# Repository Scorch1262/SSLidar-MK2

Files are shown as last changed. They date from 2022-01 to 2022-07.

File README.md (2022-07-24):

# SSLidar-MK2
Solid State Lidar

 Funktionen (Software V1.0) [F]:
	( Ab Board V2.0 )
- MCC UART1 Funktion
- MCC I2C Funktion
- MCC SPI Funktion
- MCC Fatfs Funktion
- Sensorauswertung 8x Time-of-Flight (VL53L0X)
- Speicherung der Sensordaten auf der SD-Karte
- Weitergabe/Verteilung von UART Signalen

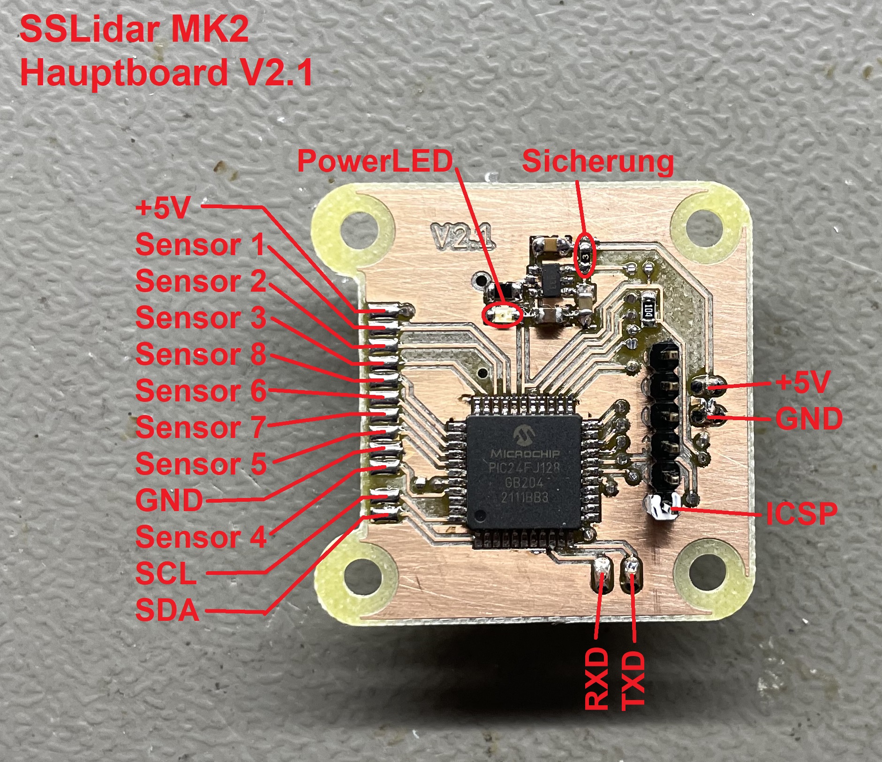
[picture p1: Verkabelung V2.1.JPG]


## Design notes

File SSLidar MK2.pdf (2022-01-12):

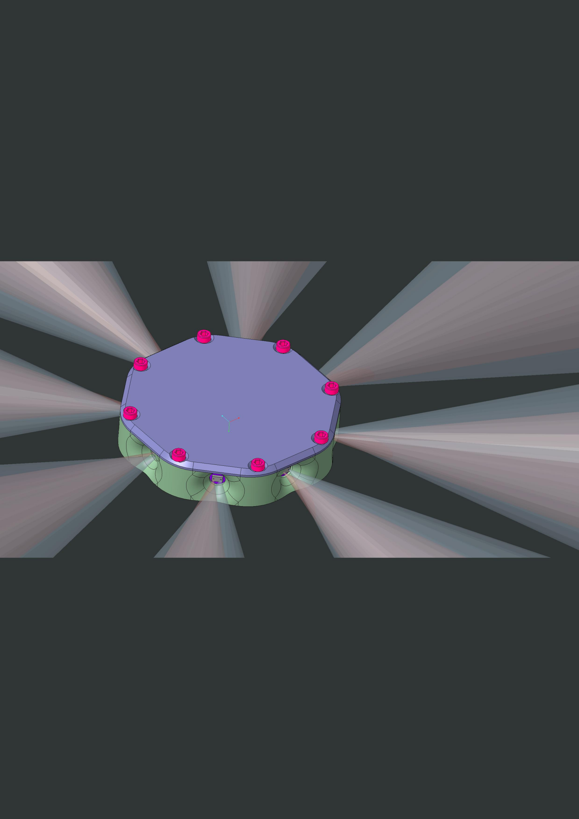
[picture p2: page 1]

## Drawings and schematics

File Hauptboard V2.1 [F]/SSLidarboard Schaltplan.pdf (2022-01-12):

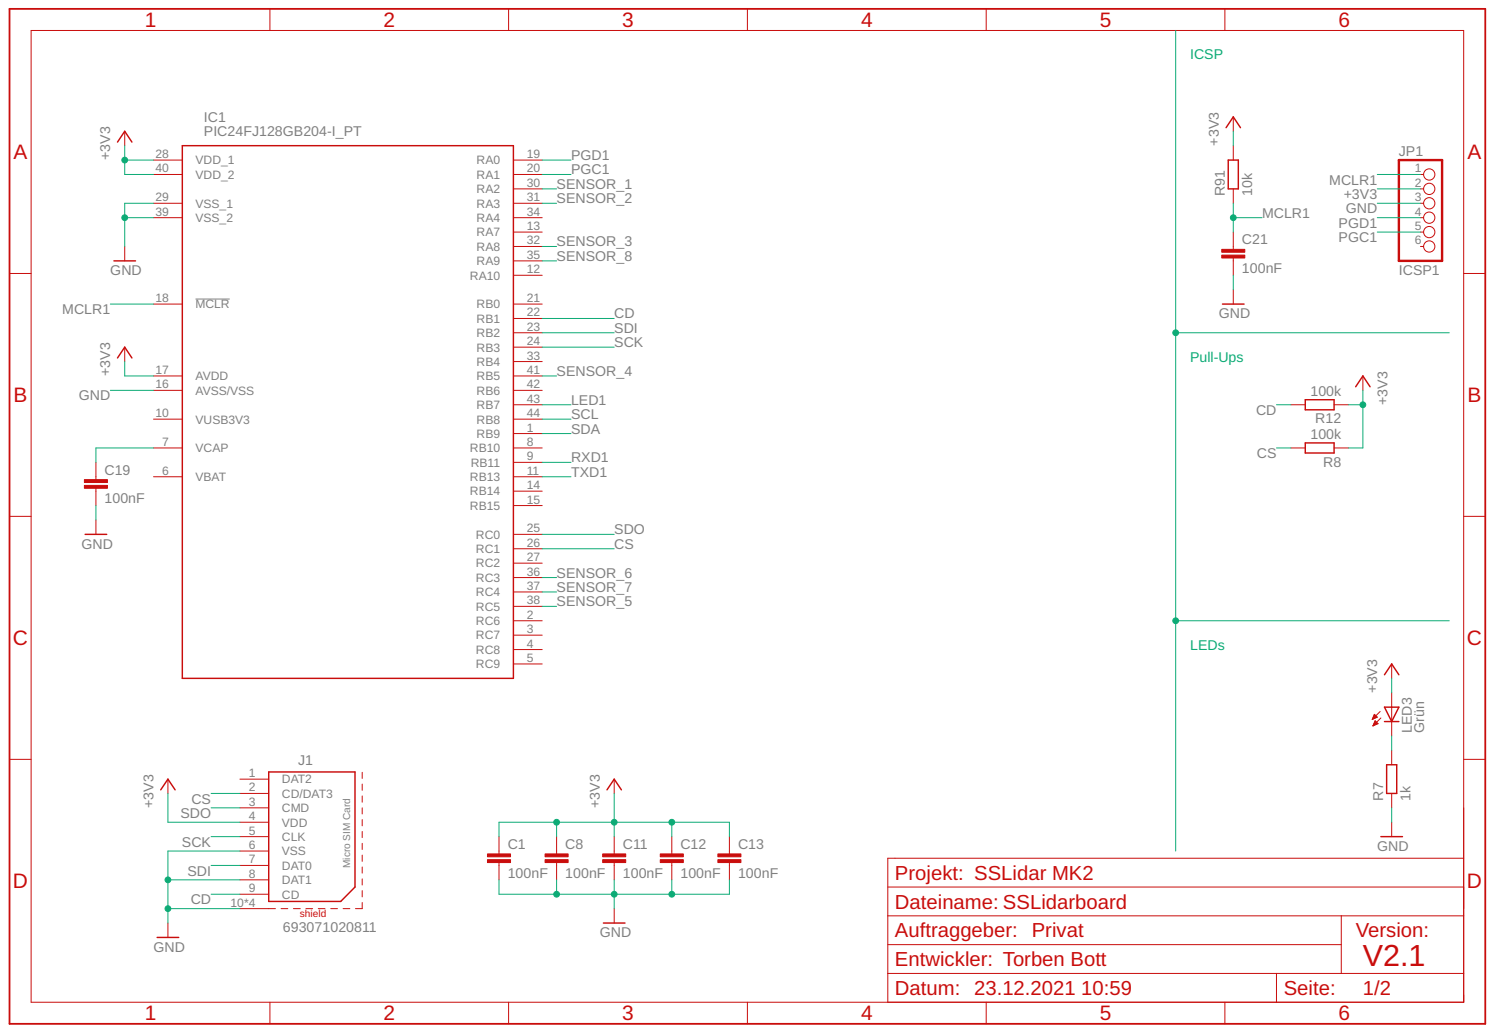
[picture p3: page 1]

Micro SIM Card +3V3 GND 100nF +3V3 GND 100nF 100nF 100nF 100nF +3V3 GND 100nF 100k 100k +3V3 +3V3 GND100nF 10k PIC24FJ128GB204-I_PT ICSP1 GND Grün 1k +3V3 693071020811 GND +3V3 C1 C8 C11 C12 C13 C19 R8 R12 C21 R91 RB9 1 RC6 2 RC7 3 RC8 4 RC9 5 VBAT 6 VCAP 7 RB10 8 RB11 9 VUSB3V3 10 RB13 11 RA10 12 RA7 13 RB14 14 RB15 15 AVSS/VSS 16 AVDD 17 MCLR 18 RA0 19 RA1 20 RB0 21 RB1 22 RB4 33 RA8 32 RA3 31 RA2 30 VSS_1 29 VDD_1 28 RC2 27 RC1 26 RC0 25 RB3 24 RB2 23 RB8 44 RB7 43 RB6 42 RB5 41 VDD_2 40 VSS_2 39 RC5 38 RC4 37 RC3 36 RA9 35 RA4 34 IC1 123456 JP1LED3 R7DAT2 1 CD/DAT3 2 CMD 3 VDD 4 CLK 5 VSS 6 DAT0 7 DAT1 8 CD 9 10*4 J1 +3V3 GND GND LED1 SCK SCK CS CS CS SDO SDO SDI SDI CD CD CD SCL SDA PGD1 PGD1 PGC1 PGC1 MCLR1 MCLR1 MCLR1 RXD1 TXD1 SENSOR_4 SENSOR_3 SENSOR_2 SENSOR_1 SENSOR_5 SENSOR_6 SENSOR_7 SENSOR_8 SSLidar MK2 Privat Torben Bott V2.1 ABCD 1 2 3 4 5 6 ABCD 1 2 3 4 5 6 Datum: Seite: Version: Dateiname: Auftraggeber: Entwickler: Projekt: 23.12.2021 10:59 1/2 SSLidarboard shield LEDs ICSP Pull-Ups

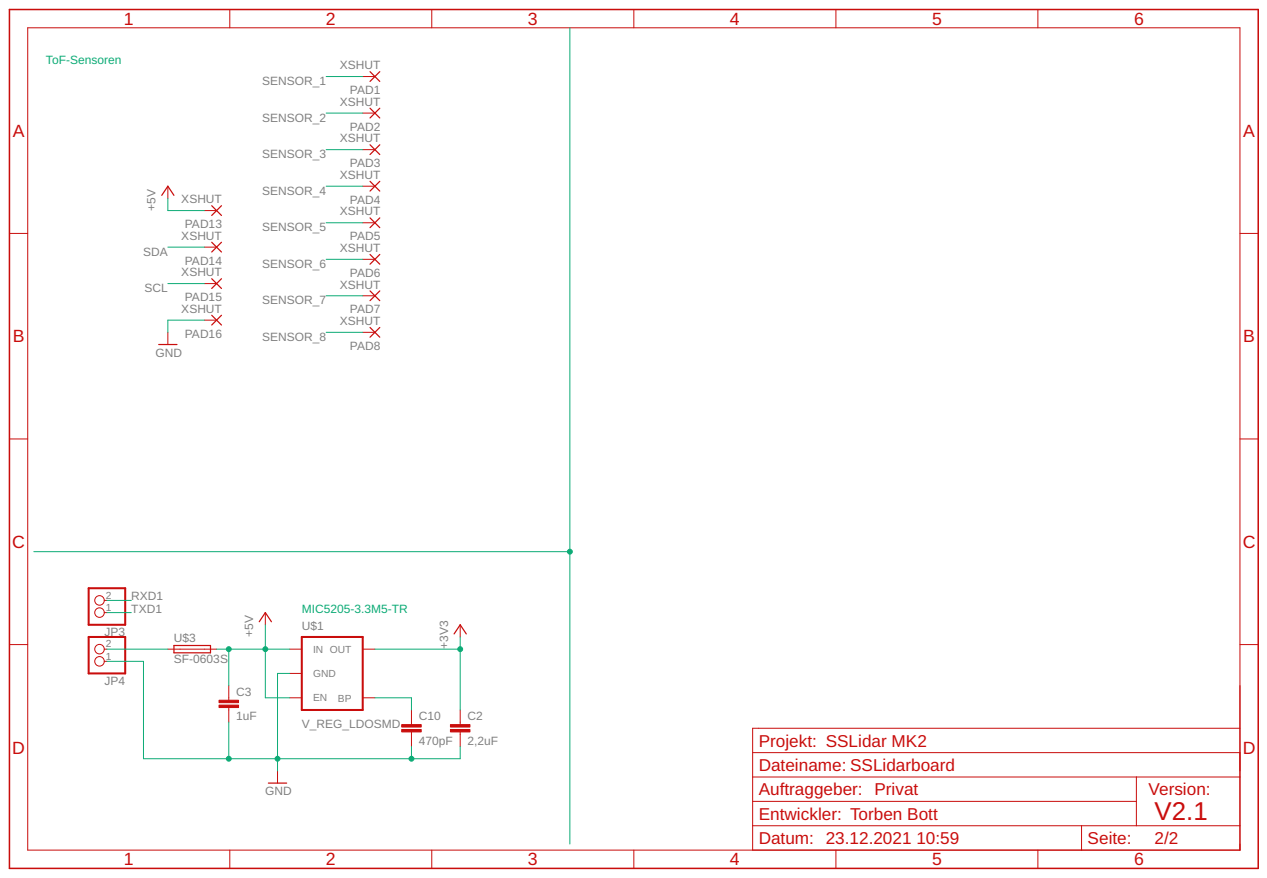
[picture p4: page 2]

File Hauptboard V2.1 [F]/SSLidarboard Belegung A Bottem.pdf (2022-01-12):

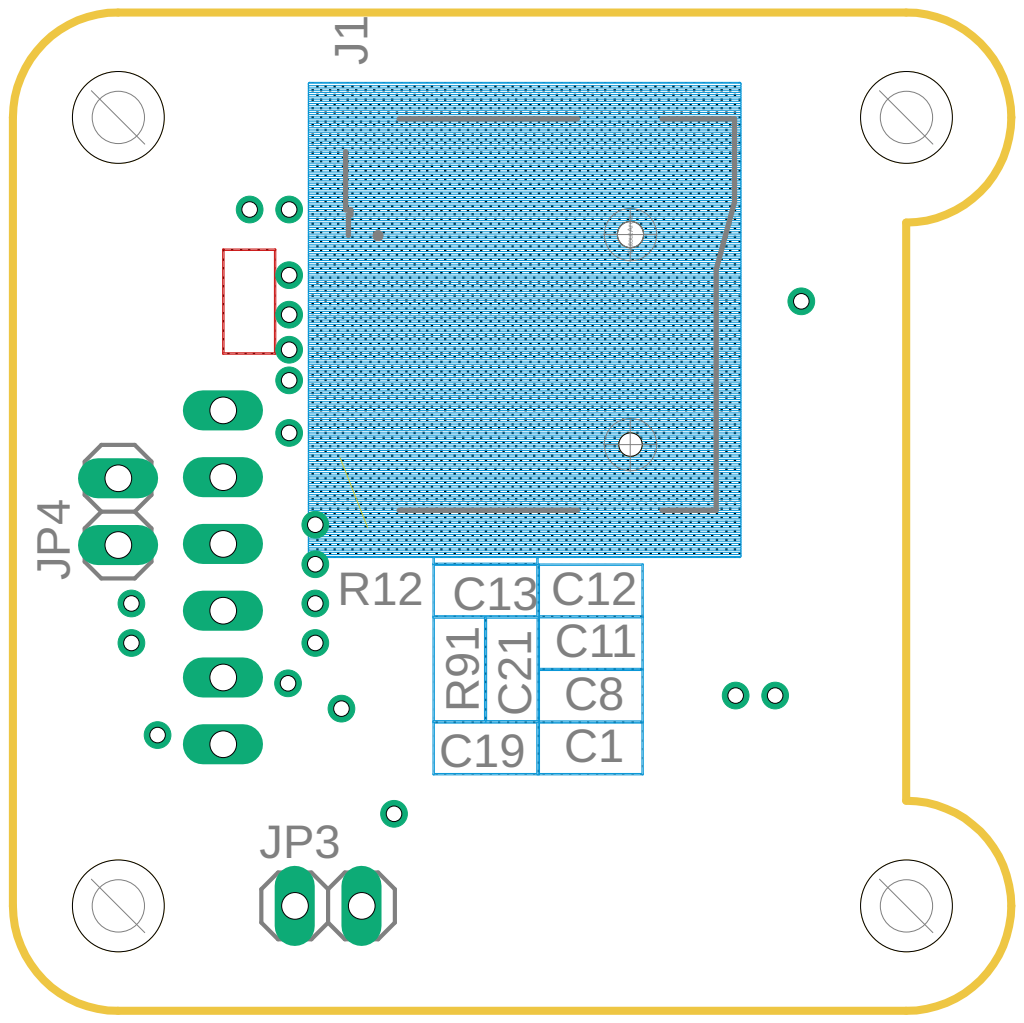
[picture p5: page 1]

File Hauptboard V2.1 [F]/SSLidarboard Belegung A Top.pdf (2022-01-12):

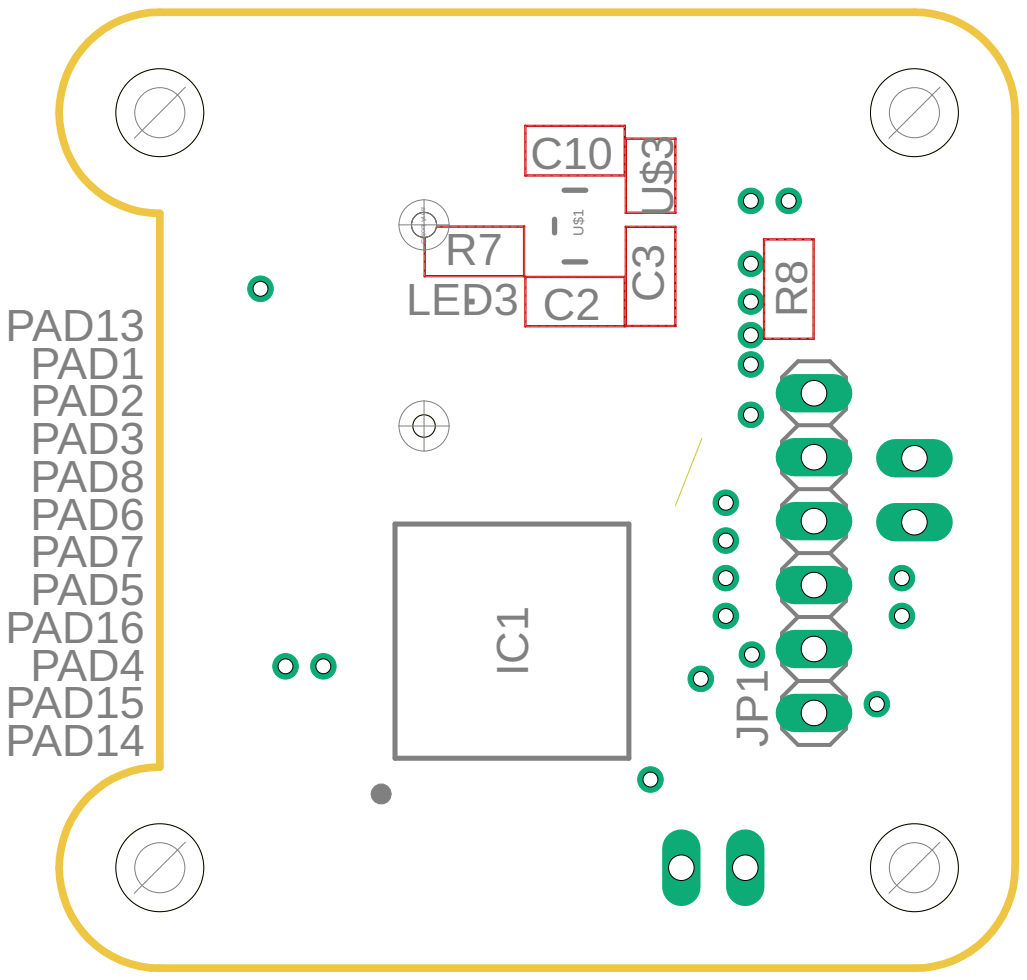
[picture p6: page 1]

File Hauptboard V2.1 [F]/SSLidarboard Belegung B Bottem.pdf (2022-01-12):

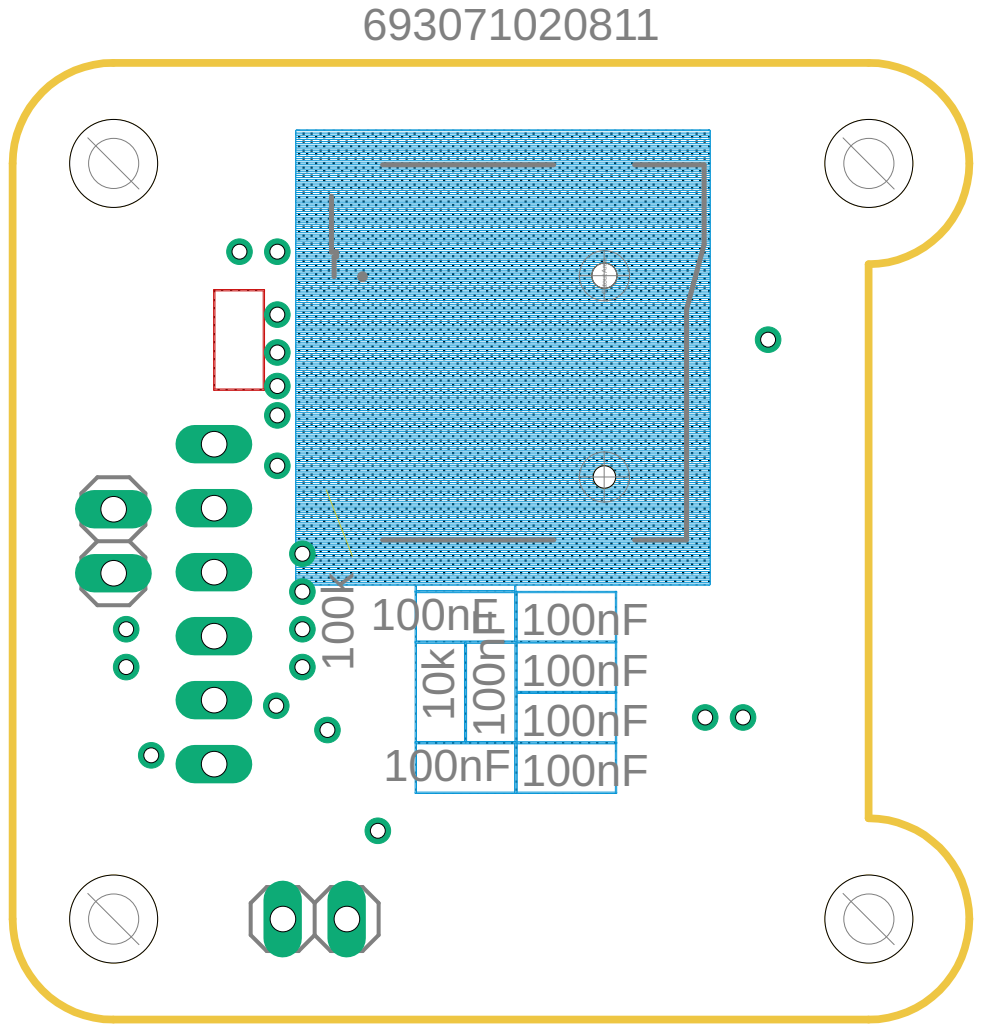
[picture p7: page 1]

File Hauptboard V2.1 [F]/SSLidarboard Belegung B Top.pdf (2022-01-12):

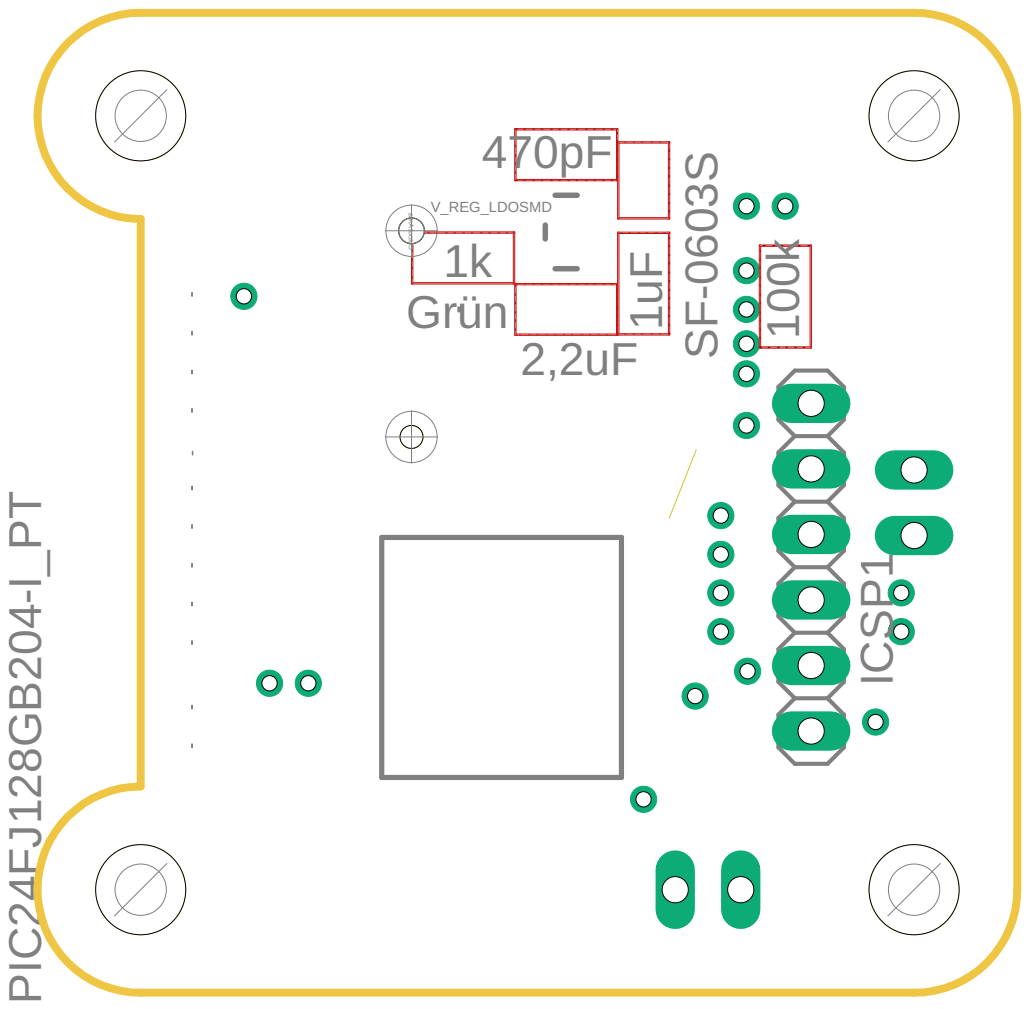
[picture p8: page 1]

100k PIC24FJ128GB204-I_PT ICSP1 Grün 1k V_REG_LDOSMD 2,2uF 470pF 1uF SF-0603S Cutout Area

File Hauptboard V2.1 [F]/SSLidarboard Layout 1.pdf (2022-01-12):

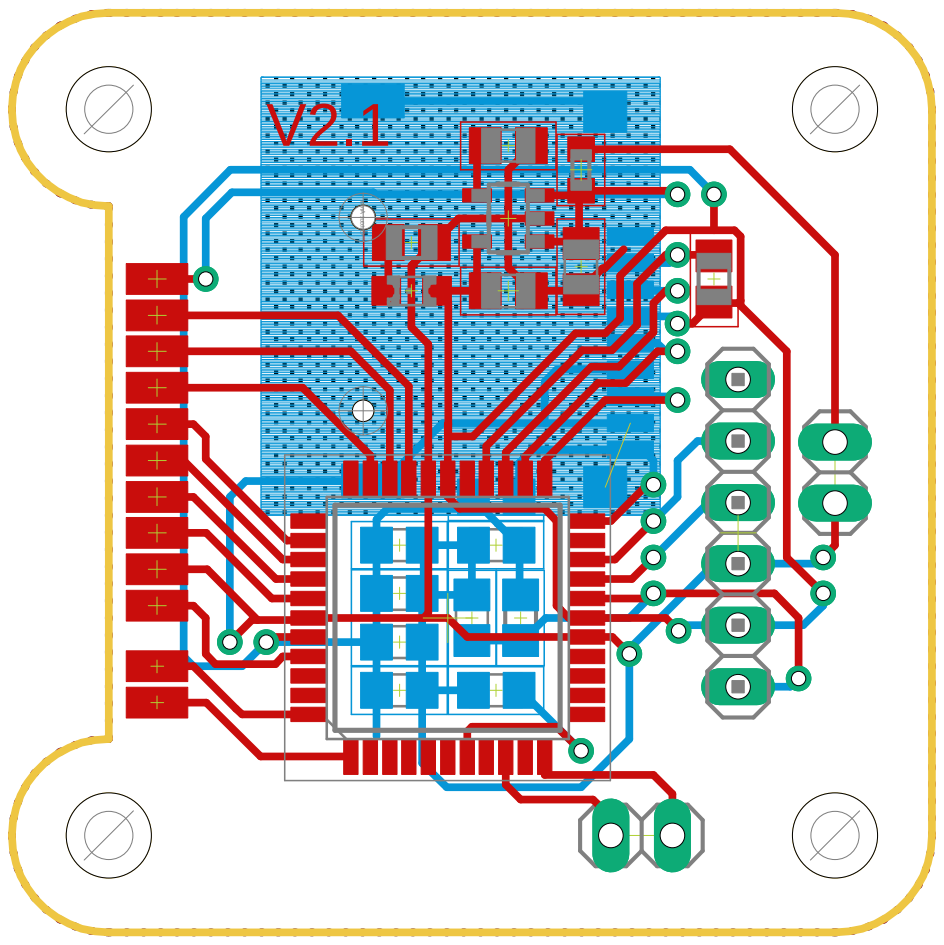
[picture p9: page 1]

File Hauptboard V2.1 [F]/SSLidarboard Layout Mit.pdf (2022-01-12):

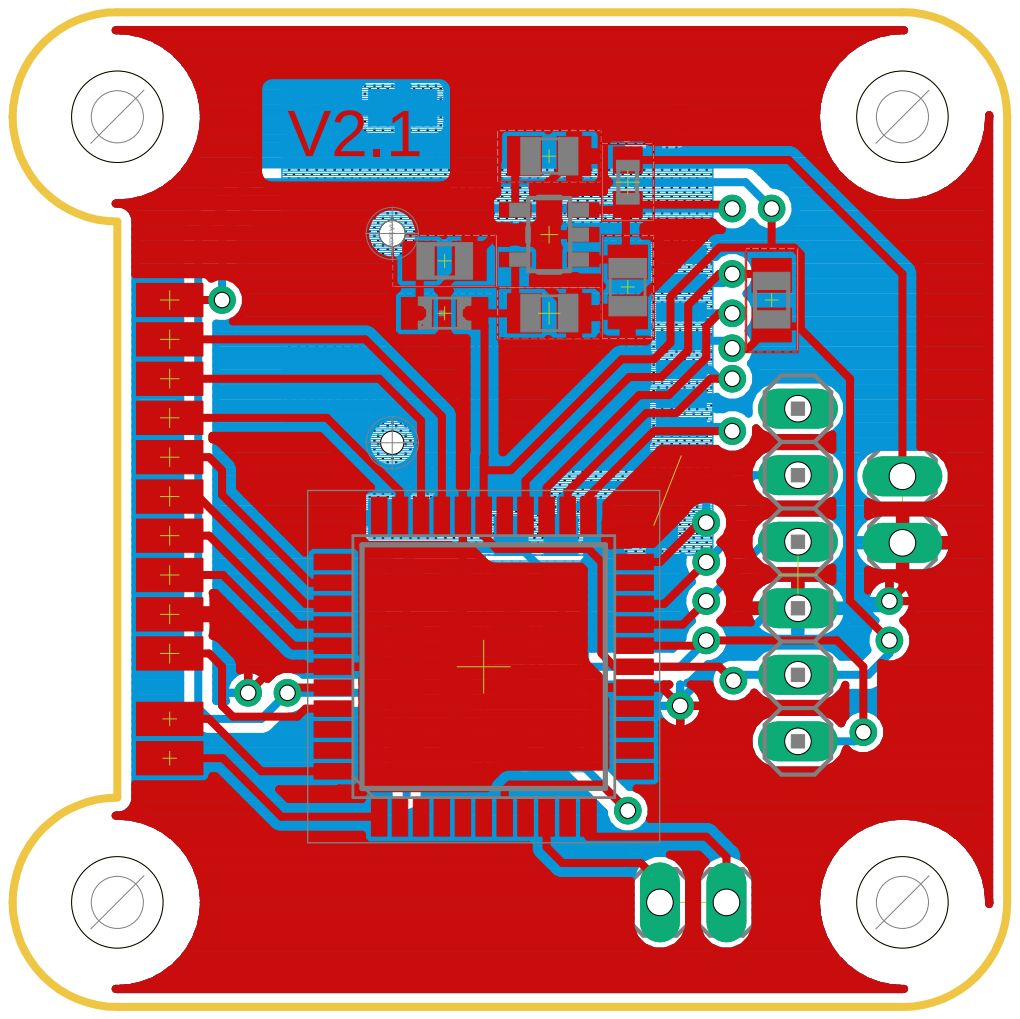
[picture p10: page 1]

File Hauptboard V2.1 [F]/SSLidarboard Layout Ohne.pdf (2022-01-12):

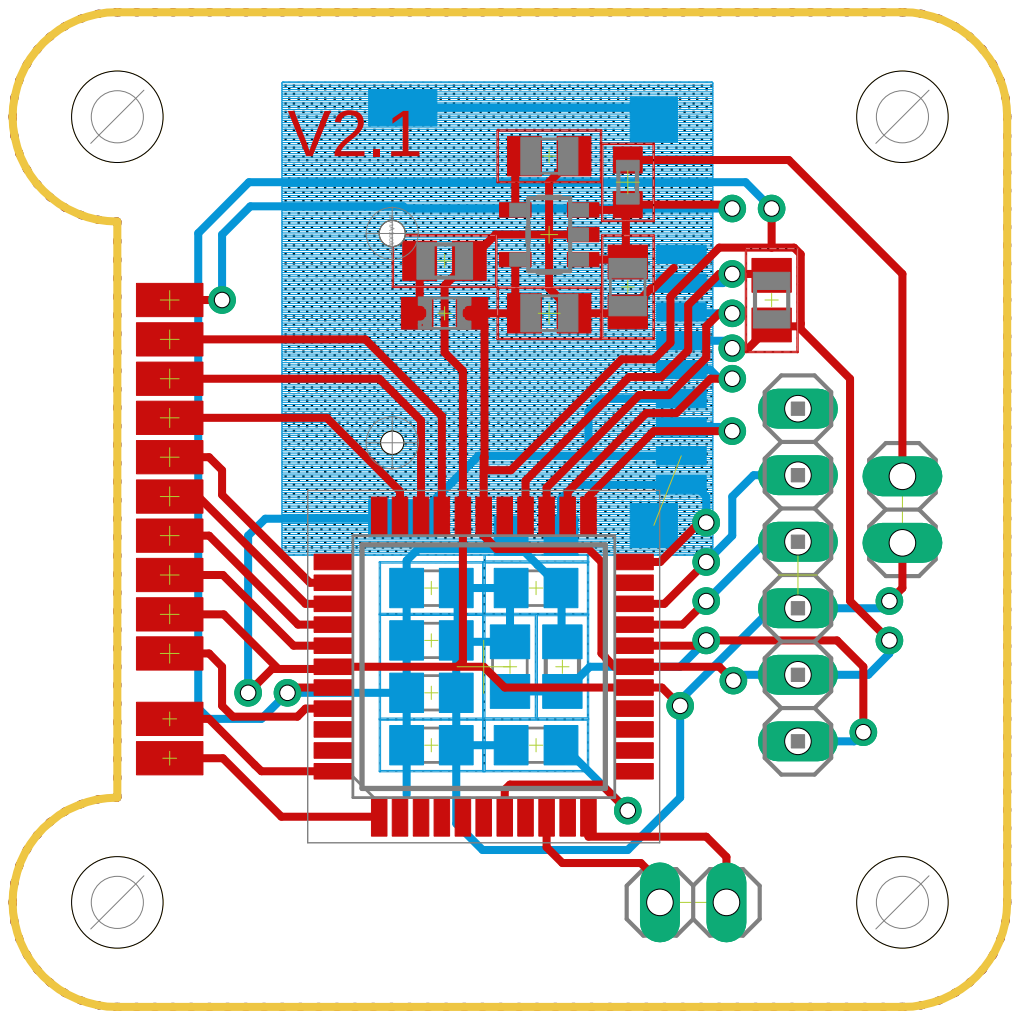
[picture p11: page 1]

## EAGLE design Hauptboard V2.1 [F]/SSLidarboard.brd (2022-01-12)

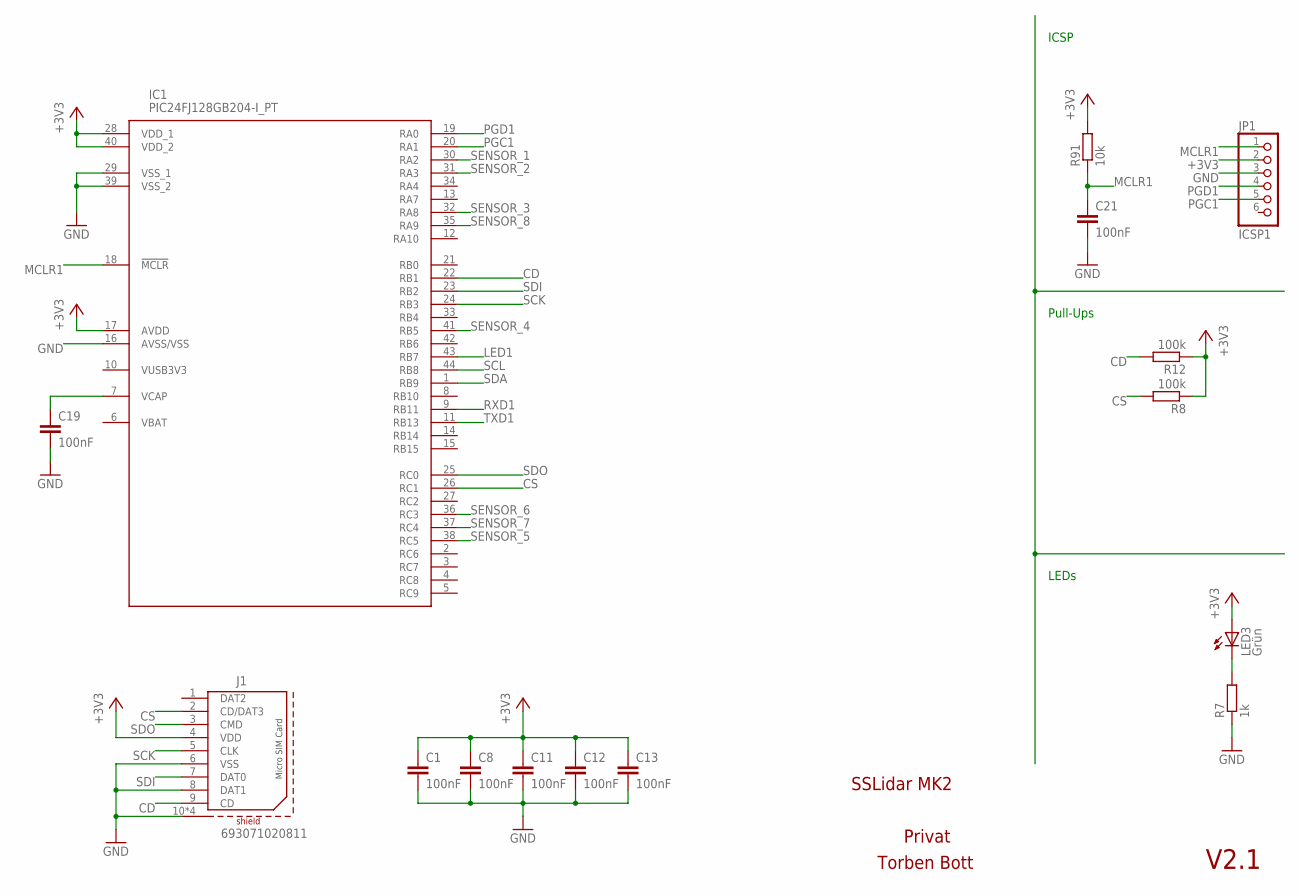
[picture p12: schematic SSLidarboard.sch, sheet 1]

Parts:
C1, C8, C11, C12, C13, C19, C21: 100nF; C0805
IC1: PIC24FJ128GB204-I_PT; QFP80P1200X1200X120-44N
J1: 693071020811
JP1: ICSP1; 1X06
LED3: Grün; CHIPLED_0805
R7: 1k; R0805
R8, R12: 100k; R0805
R91: 10k; R0805

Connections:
+3V3: C1.1, C8.1, C11.1, C12.1, C13.1, IC1.17 (AVDD), IC1.28 (VDD_1), IC1.40 (VDD_2), J1.4 (VDD), JP1.2, LED3.A, R8.1, R12.1, R91.2; also elsewhere on the board
CD: IC1.22 (RB1), J1.9 (CD), R12.2
CS: IC1.26 (RC1), J1.2 (CD/DAT3), R8.2
GND: C1.2, C8.2, C11.2, C12.2, C13.2, C19.2, C21.2, IC1.16 (AVSS/VSS), IC1.29 (VSS_1), IC1.39 (VSS_2), J1.6 (VSS), J1.8 (DAT1), J1.10 (SHIELD), J1.11 (SHIELD), J1.12 (SHIELD), J1.13 (SHIELD), JP1.3, R7.1; also elsewhere on the board
LED1: IC1.43 (RB7)
MCLR1: C21.1, IC1.18 (!MCLR), JP1.1, R91.1
unnamed: LED3.C, R7.2
unnamed: C19.1, IC1.7 (VCAP)
PGC1: IC1.20 (RA1), JP1.5
PGD1: IC1.19 (RA0), JP1.4
RXD1: IC1.9 (RB11); also elsewhere on the board
SCK: IC1.24 (RB3), J1.5 (CLK)
SCL: IC1.44 (RB8); also elsewhere on the board
SDA: IC1.1 (RB9); also elsewhere on the board
SDI: IC1.23 (RB2), J1.7 (DAT0)
SDO: IC1.25 (RC0), J1.3 (CMD)
SENSOR_1: IC1.30 (RA2); also elsewhere on the board
SENSOR_2: IC1.31 (RA3); also elsewhere on the board
SENSOR_3: IC1.32 (RA8); also elsewhere on the board
SENSOR_4: IC1.41 (RB5); also elsewhere on the board
SENSOR_5: IC1.38 (RC5); also elsewhere on the board
SENSOR_6: IC1.36 (RC3); also elsewhere on the board
SENSOR_7: IC1.37 (RC4); also elsewhere on the board
SENSOR_8: IC1.35 (RA9); also elsewhere on the board
TXD1: IC1.11 (RB13); also elsewhere on the board

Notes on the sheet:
SSLidar MK2
Privat
Torben Bott
V2.1
LEDs
ICSP
Pull-Ups

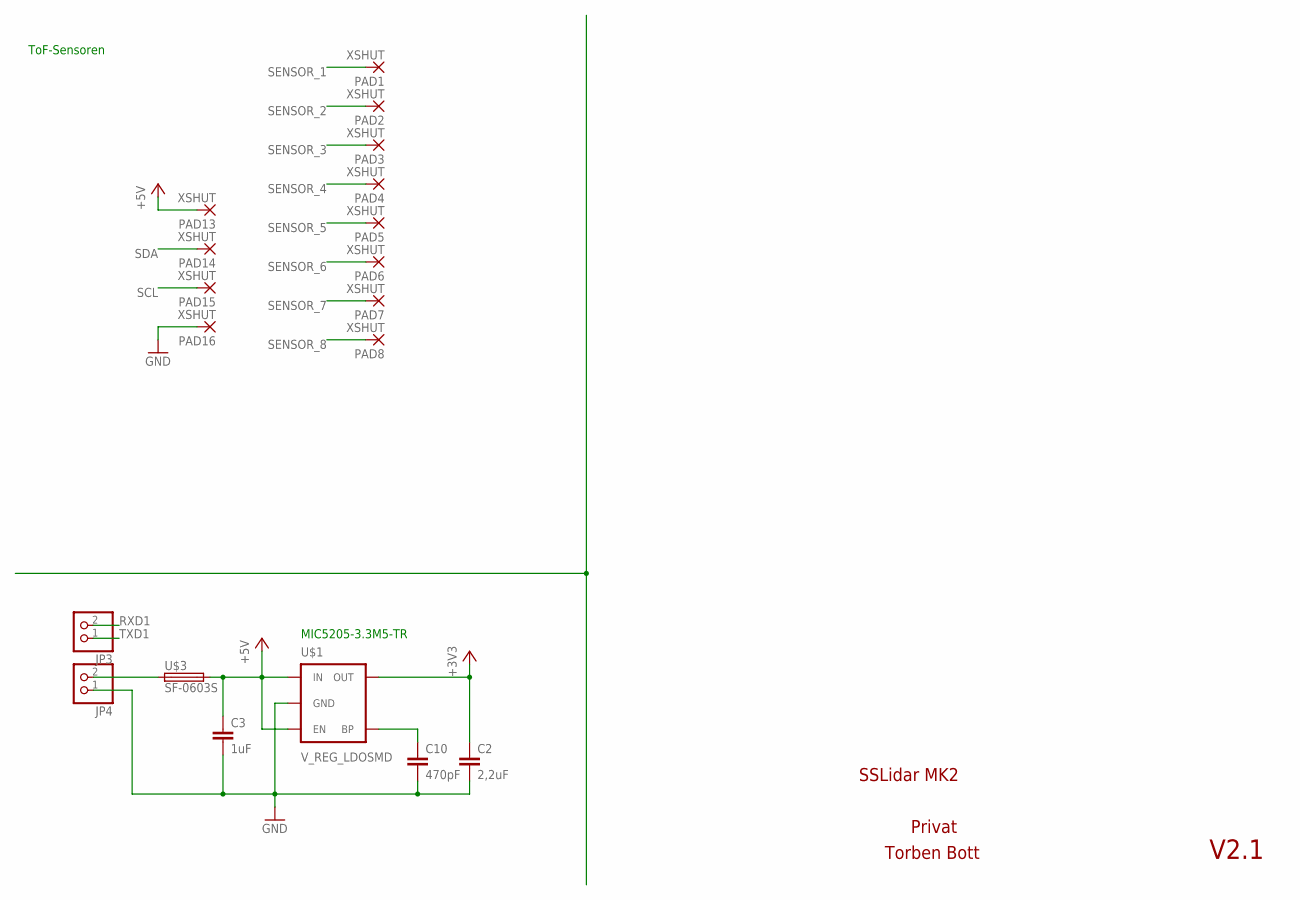
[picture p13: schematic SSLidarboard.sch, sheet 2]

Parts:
C2: 2,2uF; C0805
C3: 1uF; C0805
C10: 470pF; C0805
JP3, JP4: PINHD-1X2; 1X02
PAD1, PAD2, PAD3, PAD4, PAD5, PAD6, PAD7, PAD8, PAD13, PAD14, PAD15, PAD16: XSHUT; SMD1,27-2,54
U$1: V_REG_LDOSMD; SOT23-5
U$3: SF-0603S; R0603

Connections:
+3V3: C2.1, U$1.5 (OUT); also elsewhere on the board
+5V: C3.1, PAD13.1, U$1.1 (IN), U$1.3 (EN), U$3.2
GND: C2.2, C3.2, C10.2, JP4.1, PAD16.1, U$1.2 (GND); also elsewhere on the board
unnamed: JP4.2, U$3.1
unnamed: C10.1, U$1.4 (BP)
RXD1: JP3.2; also elsewhere on the board
SCL: PAD15.1; also elsewhere on the board
SDA: PAD14.1; also elsewhere on the board
SENSOR_1: PAD1.1; also elsewhere on the board
SENSOR_2: PAD2.1; also elsewhere on the board
SENSOR_3: PAD3.1; also elsewhere on the board
SENSOR_4: PAD4.1; also elsewhere on the board
SENSOR_5: PAD5.1; also elsewhere on the board
SENSOR_6: PAD6.1; also elsewhere on the board
SENSOR_7: PAD7.1; also elsewhere on the board
SENSOR_8: PAD8.1; also elsewhere on the board
TXD1: JP3.1; also elsewhere on the board

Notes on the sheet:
Privat
Torben Bott
V2.1
ToF-Sensoren
SSLidar MK2
MIC5205-3.3M5-TR

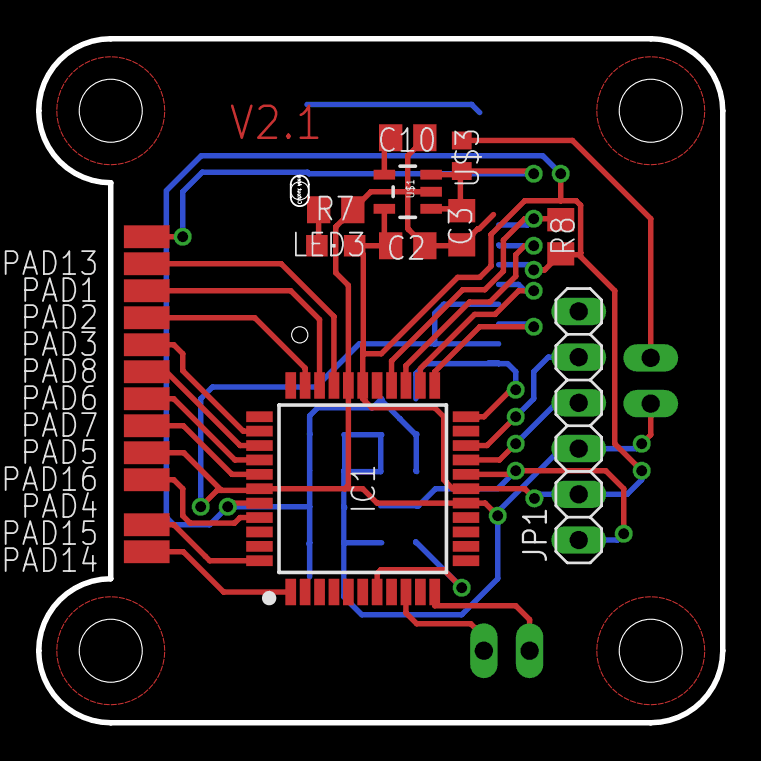
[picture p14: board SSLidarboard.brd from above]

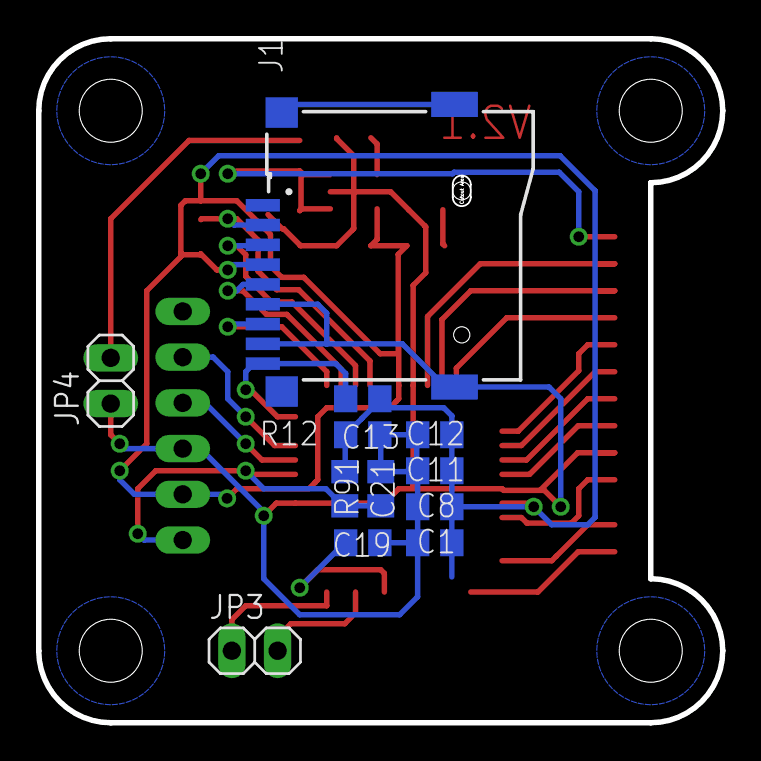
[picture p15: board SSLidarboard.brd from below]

Board: 2 copper layers, 38.0 x 38.0 mm, 34 parts (12 on the bottom side), 27 nets.

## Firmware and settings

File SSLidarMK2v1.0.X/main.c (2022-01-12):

/**
  Generated main.c file from MPLAB Code Configurator

  @Company
    Microchip Technology Inc.

  @File Name
    main.c

  @Summary
    This is the generated main.c using PIC24 / dsPIC33 / PIC32MM MCUs.

  @Description
    This source file provides main entry point for system initialization and application code development.
    Generation Information :
        Product Revision  :  PIC24 / dsPIC33 / PIC32MM MCUs - 1.170.0
        Device            :  PIC24FJ128GB204
    The generated drivers are tested against the following:
        Compiler          :  XC16 v1.61
        MPLAB 	          :  MPLAB X v5.45
*/

/*
    (c) 2020 Microchip Technology Inc. and its subsidiaries. You may use this
    software and any derivatives exclusively with Microchip products.

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
    IN NO EVENT WILL MICROCHIP BE LIABLE FOR ANY INDIRECT, SPECIAL, PUNITIVE,
    INCIDENTAL OR CONSEQUENTIAL LOSS, DAMAGE, COST OR EXPENSE OF ANY KIND
    WHATSOEVER RELATED TO THE SOFTWARE, HOWEVER CAUSED, EVEN IF MICROCHIP HAS
    BEEN ADVISED OF THE POSSIBILITY OR THE DAMAGES ARE FORESEEABLE. TO THE
    FULLEST EXTENT ALLOWED BY LAW, MICROCHIP'S TOTAL LIABILITY ON ALL CLAIMS IN
    ANY WAY RELATED TO THIS SOFTWARE WILL NOT EXCEED THE AMOUNT OF FEES, IF ANY,
    THAT YOU HAVE PAID DIRECTLY TO MICROCHIP FOR THIS SOFTWARE.

    MICROCHIP PROVIDES THIS SOFTWARE CONDITIONALLY UPON YOUR ACCEPTANCE OF THESE
    TERMS.
*/

/**
  Section: Included Files
*/
#define FCY 32000000UL 
#include <assert.h>
#include <stdbool.h>
#include "mcc_generated_files/system.h"
#include <stdio.h>
#include <stdlib.h>
#include <libpic30.h>
#include <xc.h>
#include <string.h>
#include "mcc_generated_files/mcc.h"
#include "mcc_generated_files/fatfs/fatfs.h"
#include "command.h"
#include "vl53l0x.h"

#if defined(__dsPIC33E__)
	#include <p33exxxx.h>
#elif defined(__dsPIC33F__)
	#include <p33fxxxx.h>
#elif defined(__dsPIC30F__)
	#include <p30fxxxx.h>
#elif defined(__PIC24E__)
	#include <p24exxxx.h>
#elif defined(__PIC24H__)
	#include <p24hxxxx.h>
#elif defined(__PIC24F__) || defined(__PIC24FK__)
	#include <p24fxxxx.h>
#endif

#define VL53L0X_Add_01      0x11                                        // ToF-Sensor 
#define VL53L0X_Add_02      0x12                                        // ToF-Sensor 
#define VL53L0X_Add_03      0x13                                        // ToF-Sensor 
#define VL53L0X_Add_04      0x14                                        // ToF-Sensor 
#define VL53L0X_Add_05      0x15                                        // ToF-Sensor 
#define VL53L0X_Add_06      0x16                                        // ToF-Sensor 
#define VL53L0X_Add_07      0x17                                        // ToF-Sensor 
#define VL53L0X_Add_08      0x18                                        // ToF-Sensor 

int      i;                                                     // definiert "i"
float    range_mm_0;                                            // definiert "range_mm_1"       ToF-Sensor 
float    range_cm_0;                                            // definiert "range_cm_1"       ToF-Sensor 
float    range_mm_45;                                           // definiert "range_mm_2"       ToF-Sensor 
float    range_cm_45;                                           // definiert "range_cm_2"       ToF-Sensor 
float    range_mm_90;                                           // definiert "range_mm_3"       ToF-Sensor 
float    range_cm_90;                                           // definiert "range_cm_3"       ToF-Sensor 
float    range_mm_135;                                          // definiert "range_mm_4"       ToF-Sensor 
float    range_cm_135;                                          // definiert "range_cm_4"       ToF-Sensor
float    range_mm_180;                                          // definiert "range_mm_5"       ToF-Sensor 
float    range_cm_180;                                          // definiert "range_cm_5"       ToF-Sensor 
float    range_mm_225;                                          // definiert "range_mm_6"       ToF-Sensor 
float    range_cm_225;                                          // definiert "range_cm_6"       ToF-Sensor 
float    range_mm_270;                                          // definiert "range_mm_7"       ToF-Sensor 
float    range_cm_270;                                          // definiert "range_cm_7"       ToF-Sensor 
float    range_mm_315;                                          // definiert "range_mm_8"       ToF-Sensor 
float    range_cm_315;                                          // definiert "range_cm_8"       ToF-Sensor
char     buffer;                                                // defeniert "buffer"

/*
                         Main application
 */
int main(void){                                                 // "main"
    SYSTEM_Initialize();                                        // initialize the device
    Sensor_01_SetLow();                                         // setzt "Sensor_01" auf 0
    Sensor_02_SetLow();                                         // setzt "Sensor_02" auf 0
    Sensor_03_SetLow();                                         // setzt "Sensor_03" auf 0
    Sensor_04_SetLow();                                         // setzt "Sensor_04" auf 0
    Sensor_05_SetLow();                                         // setzt "Sensor_05" auf 0
    Sensor_06_SetLow();                                         // setzt "Sensor_06" auf 0
    Sensor_07_SetLow();                                         // setzt "Sensor_07" auf 0
    Sensor_08_SetLow();                                         // setzt "Sensor_08" auf 0
    __delay_ms(500);                                            // warte 500ms
    ToF_Init();                                                 // ruft "ToF_Init" auf

    while(1){                                                   // Endlosschleife
        range_mm_0   = VL53L0X_Millimeter_GetValue(VL53L0X_Add_01);// schreibt ergebnis von "VL53L0X_Millimeter_GetValue" in "range_mm_01"
        range_mm_45  = VL53L0X_Millimeter_GetValue(VL53L0X_Add_02);// schreibt ergebnis von "VL53L0X_Millimeter_GetValue" in "range_mm_02"
        range_mm_90  = VL53L0X_Millimeter_GetValue(VL53L0X_Add_03);// schreibt ergebnis von "VL53L0X_Millimeter_GetValue" in "range_mm_03"
        range_mm_135 = VL53L0X_Millimeter_GetValue(VL53L0X_Add_04);// schreibt ergebnis von "VL53L0X_Millimeter_GetValue" in "range_mm_04"
        range_mm_180 = VL53L0X_Millimeter_GetValue(VL53L0X_Add_05);// schreibt ergebnis von "VL53L0X_Millimeter_GetValue" in "range_mm_05"
        range_mm_225 = VL53L0X_Millimeter_GetValue(VL53L0X_Add_06);// schreibt ergebnis von "VL53L0X_Millimeter_GetValue" in "range_mm_06"
        range_mm_270 = VL53L0X_Millimeter_GetValue(VL53L0X_Add_07);// schreibt ergebnis von "VL53L0X_Millimeter_GetValue" in "range_mm_07"
        range_mm_315 = VL53L0X_Millimeter_GetValue(VL53L0X_Add_08);// schreibt ergebnis von "VL53L0X_Millimeter_GetValue" in "range_mm_08"
        
        Wert_korrektur();                                       // ruft "Wert_korrektur" auf
        FatFs_Tasks();                                          // ruft "FatFs_Tasks" auf
        
        printf(" W0=   %.0fmm\r\n W45=  %.0fmm\r\n W90=  %.0fmm\r\n W135= %.0fmm\r\n W180= %.0fmm\r\n W225= %.0fmm\r\n W270= %.0fmm\r\n W315= %.0fmm\r\n\r\n",         // 
            range_mm_0,                                         // 
            range_mm_45,                                        // 
            range_mm_90,                                        // 
            range_mm_135,                                       //
            range_mm_180,                                       // 
            range_mm_225,                                       // 
            range_mm_270,                                       // 
            range_mm_315);                                      // 

        __delay_ms(50);                                         // warte 50ms 
    }                                                           // 
    return 1;                                                   // 
}                                                               // 
/**
 End of File
*/

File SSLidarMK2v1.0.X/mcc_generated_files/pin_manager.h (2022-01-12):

/**
  PIN MANAGER Generated Driver File

  @Company:
    Microchip Technology Inc.

  @File Name:
    pin_manager.h

  @Summary:
    This is the generated manager file for the PIC24 / dsPIC33 / PIC32MM MCUs device.  This manager
    configures the pins direction, initial state, analog setting.
    The peripheral pin select, PPS, configuration is also handled by this manager.

  @Description:
    This source file provides implementations for PIN MANAGER.
    Generation Information :
        Product Revision  :  PIC24 / dsPIC33 / PIC32MM MCUs - 1.170.0
        Device            :  PIC24FJ128GB204
    The generated drivers are tested against the following:
        Compiler          :  XC16 v1.61
        MPLAB 	          :  MPLAB X v5.45
*/

/*
    (c) 2020 Microchip Technology Inc. and its subsidiaries. You may use this
    software and any derivatives exclusively with Microchip products.

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
    IN NO EVENT WILL MICROCHIP BE LIABLE FOR ANY INDIRECT, SPECIAL, PUNITIVE,
    INCIDENTAL OR CONSEQUENTIAL LOSS, DAMAGE, COST OR EXPENSE OF ANY KIND
    WHATSOEVER RELATED TO THE SOFTWARE, HOWEVER CAUSED, EVEN IF MICROCHIP HAS
    BEEN ADVISED OF THE POSSIBILITY OR THE DAMAGES ARE FORESEEABLE. TO THE
    FULLEST EXTENT ALLOWED BY LAW, MICROCHIP'S TOTAL LIABILITY ON ALL CLAIMS IN
    ANY WAY RELATED TO THIS SOFTWARE WILL NOT EXCEED THE AMOUNT OF FEES, IF ANY,
    THAT YOU HAVE PAID DIRECTLY TO MICROCHIP FOR THIS SOFTWARE.

    MICROCHIP PROVIDES THIS SOFTWARE CONDITIONALLY UPON YOUR ACCEPTANCE OF THESE
    TERMS.
*/

#ifndef _PIN_MANAGER_H
#define _PIN_MANAGER_H
/**
    Section: Includes
*/
#include <xc.h>

/**
    Section: Device Pin Macros
*/
/**
  @Summary
    Sets the GPIO pin, RA2, high using LATA2.

  @Description
    Sets the GPIO pin, RA2, high using LATA2.

  @Preconditions
    The RA2 must be set to an output.

  @Returns
    None.

  @Param
    None.

  @Example
    <code>
    // Set RA2 high (1)
    Sensor_01_SetHigh();
    </code>

*/
#define Sensor_01_SetHigh()          (_LATA2 = 1)
/**
  @Summary
    Sets the GPIO pin, RA2, low using LATA2.

  @Description
    Sets the GPIO pin, RA2, low using LATA2.

  @Preconditions
    The RA2 must be set to an output.

  @Returns
    None.

  @Param
    None.

  @Example
    <code>
    // Set RA2 low (0)
    Sensor_01_SetLow();
    </code>

*/
#define Sensor_01_SetLow()           (_LATA2 = 0)
/**
  @Summary
    Toggles the GPIO pin, RA2, using LATA2.

  @Description
    Toggles the GPIO pin, RA2, using LATA2.

  @Preconditions
    The RA2 must be set to an output.

  @Returns
    None.

  @Param
    None.

  @Example
    <code>
    // Toggle RA2
    Sensor_01_Toggle();
    </code>

*/
#define Sensor_01_Toggle()           (_LATA2 ^= 1)
/**
  @Summary
    Reads the value of the GPIO pin, RA2.

  @Description
    Reads the value of the GPIO pin, RA2.

  @Preconditions
    None.

  @Returns
    None.

  @Param
    None.

  @Example
    <code>
    uint16_t portValue;

    // Read RA2
    postValue = Sensor_01_GetValue();
    </code>

*/
#define Sensor_01_GetValue()         _RA2
/**
  @Summary
    Configures the GPIO pin, RA2, as an input.

  @Description
    Configures the GPIO pin, RA2, as an input.

  @Preconditions
    None.

  @Returns
    None.

  @Param
    None.

  @Example
    <code>
    // Sets the RA2 as an input
    Sensor_01_SetDigitalInput();
    </code>

*/
#define Sensor_01_SetDigitalInput()  (_TRISA2 = 1)
/**
  @Summary
    Configures the GPIO pin, RA2, as an output.

  @Description
    Configures the GPIO pin, RA2, as an output.

  @Preconditions
    None.

  @Returns
    None.

  @Param
    None.

  @Example
    <code>
    // Sets the RA2 as an output
    Sensor_01_SetDigitalOutput();
    </code>

*/
#define Sensor_01_SetDigitalOutput() (_TRISA2 = 0)
/**
  @Summary
    Sets the GPIO pin, RA3, high using LATA3.

  @Description
    Sets the GPIO pin, RA3, high using LATA3.

  @Preconditions
    The RA3 must be set to an output.

  @Returns
    None.

  @Param
    None.

  @Example
    <code>
    // Set RA3 high (1)
    Sensor_02_SetHigh();
    </code>

*/
#define Sensor_02_SetHigh()          (_LATA3 = 1)
/**
  @Summary
    Sets the GPIO pin, RA3, low using LATA3.

  @Description
    Sets the GPIO pin, RA3, low using LATA3.

  @Preconditions
    The RA3 must be set to an output.

  @Returns
    None.

  @Param
    None.

  @Example
    <code>
    // Set RA3 low (0)
    Sensor_02_SetLow();
    </code>

*/
#define Sensor_02_SetLow()           (_LATA3 = 0)
/**
  @Summary
    Toggles the GPIO pin, RA3, using LATA3.

  @Description
    Toggles the GPIO pin, RA3, using LATA3.

  @Preconditions
    The RA3 must be set to an output.

  @Returns
    None.

  @Param
    None.

  @Example
    <code>
    // Toggle RA3
    Sensor_02_Toggle();
    </code>

*/
#define Sensor_02_Toggle()           (_LATA3 ^= 1)
/**
  @Summary
    Reads the value of the GPIO pin, RA3.

  @Description
    Reads the value of the GPIO pin, RA3.

  @Preconditions
    None.

  @Returns
    None.

  @Param
    None.

  @Example
    <code>
    uint16_t portValue;

    // Read RA3
    postValue = Sensor_02_GetValue();
    </code>

*/
#define Sensor_02_GetValue()         _RA3
/**
  @Summary
    Configures the GPIO pin, RA3, as an input.

  @Description
    Configures the GPIO pin, RA3, as an input.

  @Preconditions
    None.

  @Returns
    None.

  @Param
    None.

  @Example
    <code>
    // Sets the RA3 as an input
    Sensor_02_SetDigitalInput();
    </code>

*/
#define Sensor_02_SetDigitalInput()  (_TRISA3 = 1)
/**
  @Summary
    Configures the GPIO pin, RA3, as an output.

  @Description
    Configures the GPIO pin, RA3, as an output.

  @Preconditions
    None.

  @Returns
    None.

  @Param
    None.

  @Example
    <code>
    // Sets the RA3 as an output
    Sensor_02_SetDigitalOutput();
    </code>

*/
#define Sensor_02_SetDigitalOutput() (_TRISA3 = 0)
/**
  @Summary
    Sets the GPIO pin, RA8, high using LATA8.

  @Description
    Sets the GPIO pin, RA8, high using LATA8.

  @Preconditions
    The RA8 must be set to an output.

  @Returns
    None.

  @Param
    None.

  @Example
    <code>
    // Set RA8 high (1)
    Sensor_03_SetHigh();
    </code>

*/
#define Sensor_03_SetHigh()          (_LATA8 = 1)
/**
  @Summary
    Sets the GPIO pin, RA8, low using LATA8.

  @Description
    Sets the GPIO pin, RA8, low using LATA8.

  @Preconditions
    The RA8 must be set to an output.

  @Returns
    None.

  @Param
    None.

  @Example
    <code>
    // Set RA8 low (0)
    Sensor_03_SetLow();
    </code>

*/
#define Sensor_03_SetLow()           (_LATA8 = 0)
/**
  @Summary
    Toggles the GPIO pin, RA8, using LATA8.

  @Description
    Toggles the GPIO pin, RA8, using LATA8.

  @Preconditions
    The RA8 must be set to an output.

  @Returns
    None.

  @Param
    None.

  @Example
    <code>
    // Toggle RA8
    Sensor_03_Toggle();
    </code>
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

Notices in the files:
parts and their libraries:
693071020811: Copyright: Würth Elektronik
